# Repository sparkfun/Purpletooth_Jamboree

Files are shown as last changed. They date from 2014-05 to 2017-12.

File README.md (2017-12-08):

Purpletooth Jamboree Development Board
==================

Audio support board for the BC127 module from BlueCreation.

[Purpletooth Jamboree Development Board  
*Purpletooth Jamboree Development Board*](https://www.sparkfun.com/products/11924)

Design files and firmware files for the [Purpletooth Jamboree Development Board](https://www.sparkfun.com/products/11924).

Repository Contents
-------------------

* **/Fritzing** - Fritzing components for this board
* **/Hardware** - Eagle PCB layout files
* **/Libraries** - Library files for various platforms
* **/Production** - Files to support SparkFun production

License Information
-------------------

All contents of this repository are released under [Creative Commons Share-alike 4.0](http://creativecommons.org/licenses/by-sa/4.0/).

Authors: Mike Hord @ SparkFun Electonics

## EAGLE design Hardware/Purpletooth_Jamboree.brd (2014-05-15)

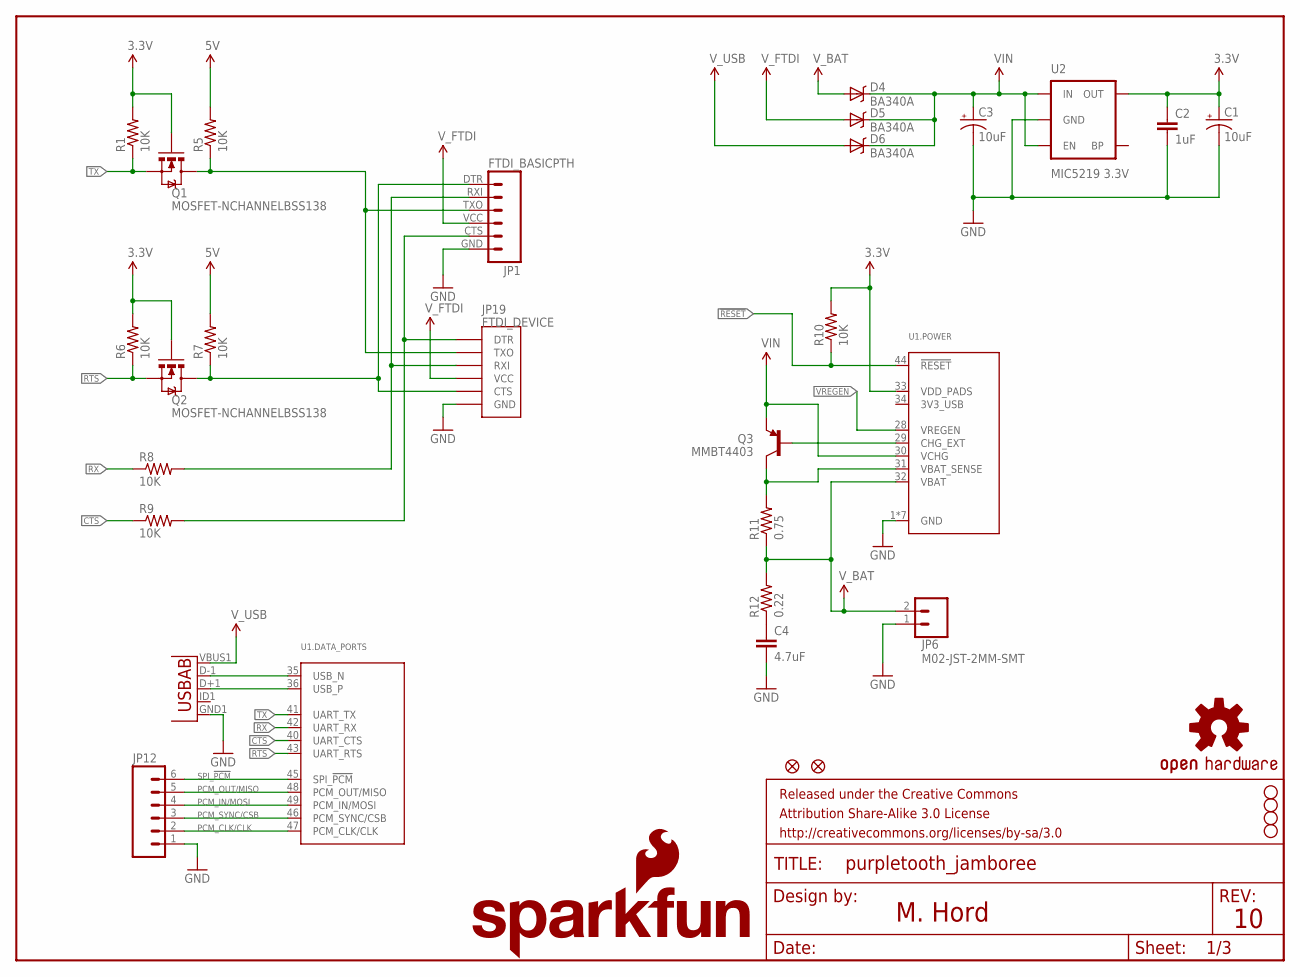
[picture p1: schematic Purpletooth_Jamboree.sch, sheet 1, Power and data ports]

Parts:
C1, C3: 10uF; EIA3216
C2: 1uF; 0805
C4: 4.7uF; 0603-CAP
D4, D5, D6: BA340A; SMA-DIODE
FID1, FID2: FIDUCIALUFIDUCIAL; MICRO-FIDUCIAL
FRAME1: FRAME-LETTER; CREATIVE_COMMONS
JP1: FTDI_BASICPTH; FTDI_BASIC
JP2: USB-ABCONN-11794; USB-AB-MICRO-SMD_V03
JP6: M02-JST-2MM-SMT; JST-2-SMD
JP12: M06SIP; 1X06
JP19: FTDI_DEVICE; FTDI_DEVICE_SIDE
LOGO1: OSHW-LOGOM; OSHW-LOGO-M
LOGO2: SFE_LOGO_NAME_FLAME.2_INCH; SFE_LOGO_NAME_FLAME_.2
Q1, Q2: MOSFET-NCHANNELBSS138; SOT23
Q3: MMBT4403; SOT23
R1, R5, R6, R7, R8, R9, R10: 10K; 0603-RES
R11: 0.75; 0805
R12: 0.22; 0805
STANDOFF1, STANDOFF2, STANDOFF3, STANDOFF4: STAND-OFF
U1: BC127EXTRA_PASTE; BC127_XTRA_PASTE
U2: MIC5219 3.3V; SOT23-5

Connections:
3.3V: C1.A (+), C2.1, Q1.1 (G), Q2.1 (G), R1.2, R6.2, R10.2, U1.33 (VDD_PADS), U2.5 (OUT); also elsewhere on the board
5V_CTS: JP1.CTS (5), JP19.P$1 (DTR), R9.2
5V_RTS: JP1.DTR (1), JP19.P$5 (CTS), Q2.3 (D), R7.1
5V_RX: JP1.RXI (2), JP19.P$3 (RXI), R8.2
5V_TX: JP1.TXO (3), JP19.P$2 (TXO), Q1.3 (D), R5.1
!RESET: R10.1, U1.44 (!RESET); also elsewhere on the board
CHG_EXT: Q3.1 (B), U1.29 (CHG_EXT)
CTS: R9.1, U1.40 (UART_CTS)
GND: C1.C (-), C2.2, C3.C (-), C4.2, JP1.GND (6), JP2.GND1 (GND), JP6.1 (2), JP12.1, JP19.P$6 (GND), U1.1 (GND), U1.2 (GND), U1.3 (GND), U1.4 (GND), U1.11 (GND), U1.22 (GND), U1.27 (GND), U2.2 (GND); also elsewhere on the board
unnamed: C4.1, R12.1
PCM_CLK/CLK: JP12.2, U1.47 (PCM_CLK/CLK)
PCM_IN/MOSI: JP12.4, U1.49 (PCM_IN/MOSI)
PCM_OUT/MISO: JP12.5, U1.48 (PCM_OUT/MISO)
PCM_SYNC/CSB: JP12.3, U1.46 (PCM_SYNC/CSB)
RTS: Q2.2 (S), R6.1, U1.43 (UART_RTS)
RX: R8.1, U1.42 (UART_RX)
SPI_!PCM: JP12.6, U1.45 (SPI_!PCM)
TX: Q1.2 (S), R1.1, U1.41 (UART_TX)
USB_N: JP2.D-1 (D-), U1.35 (USB_N)
USB_P: JP2.D+1 (D+), U1.36 (USB_P)
VBAT_SENSE: Q3.3 (C), R11.2, U1.31 (VBAT_SENSE)
VIN: C3.A (+), D4.C, D5.C, D6.C, Q3.2 (E), R5.2, R7.2, U1.30 (VCHG), U2.1 (IN), U2.3 (EN); also elsewhere on the board
VREGEN: U1.28 (VREGEN); also elsewhere on the board
V_BAT: D4.A, JP6.2 (1), R11.1, R12.2, U1.32 (VBAT)
V_FTDI: D5.A, JP1.VCC (4), JP19.P$4 (VCC)
V_USB: D6.A, JP2.VBUS1 (VBUS)

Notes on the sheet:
M. Hord

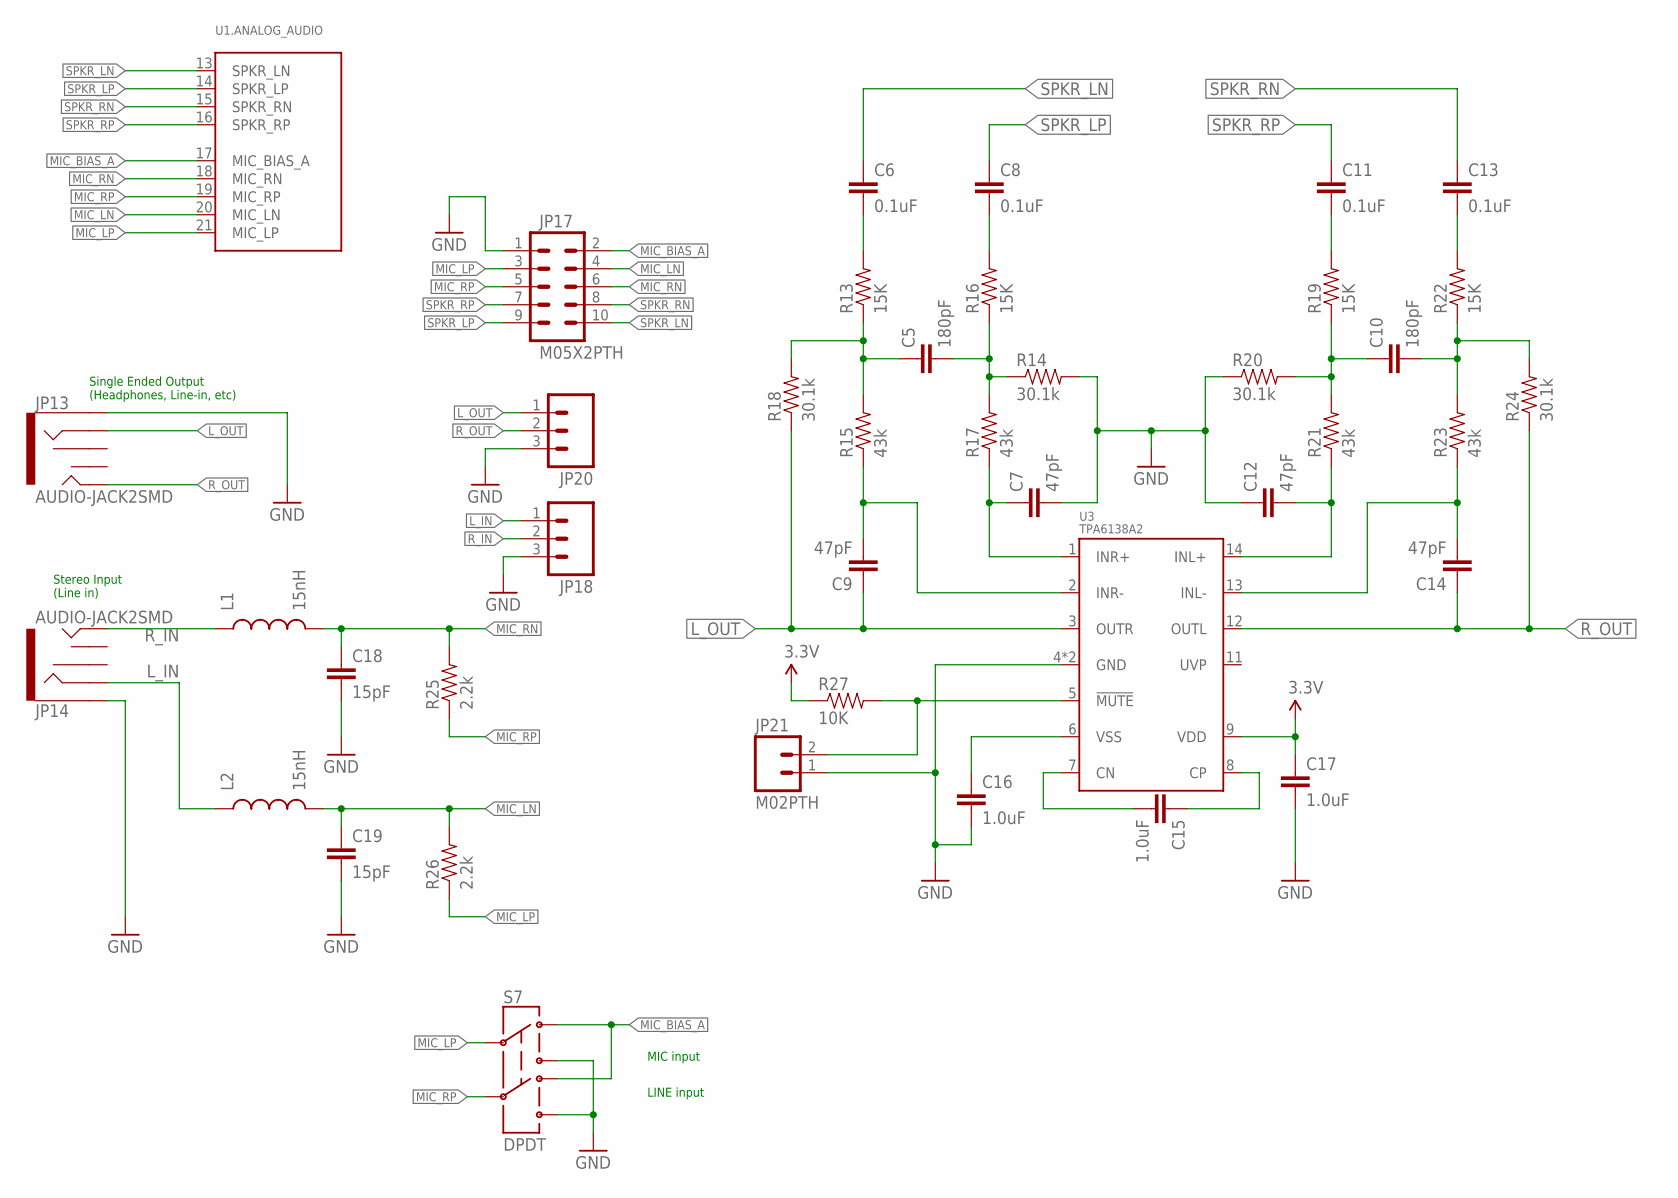
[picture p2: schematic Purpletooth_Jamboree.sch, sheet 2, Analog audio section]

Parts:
C5, C10: 180pF; 0603-CAP
C6, C8, C11, C13: 0.1uF; 0603-CAP
C7, C9, C12, C14: 47pF; 0603-CAP
C15, C16, C17: 1.0uF; 0603-CAP
C18, C19: 15pF; 0603-CAP
JP13, JP14: AUDIO-JACK2SMD; AUDIO-JACK-3.5MM-SMD
JP17: M05X2PTH; AVR_ICSP
JP18, JP20: M03PTH; 1X03
JP21: M02PTH; 1X02
L1, L2: 15nH; 0603
R13, R16, R19, R22: 15K; 0603-RES
R14, R18, R20, R24: 30.1k; 0603-RES
R15, R17, R21, R23: 43k; 0603-RES
R25, R26: 2.2k; 0603-RES
R27: 10K; 0603-RES
S7: DPDT; AYZ0202
U1: BC127EXTRA_PASTE; BC127_XTRA_PASTE
U3: TPA6138A2; TSSOP-14

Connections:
3.3V: C17.1, R27.1, U3.9 (VDD); also elsewhere on the board
GND: C7.2, C12.1, C16.2, C17.2, C18.2, C19.2, JP13.SLEEVE, JP14.SLEEVE, JP17.1, JP18.3, JP20.3, JP21.1, R14.2, R20.1, S7.3, S7.6, U3.4 (GND), U3.10 (GND); also elsewhere on the board
L_IN: JP14.RING, JP18.1, L2.1
L_OUT: C9.1, JP13.RING, JP20.1, R18.1, U3.3 (OUTR)
MIC_BIAS_A: JP17.2, S7.1, S7.4, U1.17 (MIC_BIAS_A)
MIC_LN: C19.1, JP17.4, L2.2, R26.2, U1.20 (MIC_LN)
MIC_LP: JP17.3, R26.1, S7.2, U1.21 (MIC_LP)
MIC_RN: C18.1, JP17.6, L1.2, R25.2, U1.18 (MIC_RN)
MIC_RP: JP17.5, R25.1, S7.5, U1.19 (MIC_RP)
unnamed: JP21.2, R27.2, U3.5 (!MUTE)
unnamed: C8.2, R16.2
unnamed: C6.2, R13.2
unnamed: C5.1, R13.1, R15.2, R18.2
unnamed: C9.2, R15.1, U3.2 (INR-)
unnamed: C7.1, R17.1, U3.1 (INR+)
unnamed: C5.2, R14.1, R16.1, R17.2
unnamed: C10.1, R19.1, R20.2, R21.2
unnamed: C12.2, R21.1, U3.14 (INL+)
unnamed: C11.2, R19.2
unnamed: C10.2, R22.1, R23.2, R24.2
unnamed: C13.2, R22.2
unnamed: C14.2, R23.1, U3.13 (INL-)
unnamed: C16.1, U3.6 (VSS)
unnamed: C15.2, U3.7 (CN)
unnamed: C15.1, U3.8 (CP)
R_IN: JP14.TIP, JP18.2, L1.1
R_OUT: C14.1, JP13.TIP, JP20.2, R24.1, U3.12 (OUTL)
SPKR_LN: C6.1, JP17.10, U1.13 (SPKR_LN)
SPKR_LP: C8.1, JP17.9, U1.14 (SPKR_LP)
SPKR_RN: C13.1, JP17.8, U1.15 (SPKR_RN)
SPKR_RP: C11.1, JP17.7, U1.16 (SPKR_RP)

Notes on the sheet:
Single Ended Output (Headphones, Line-in, etc)
Stereo Input (Line in)
MIC input
LINE input

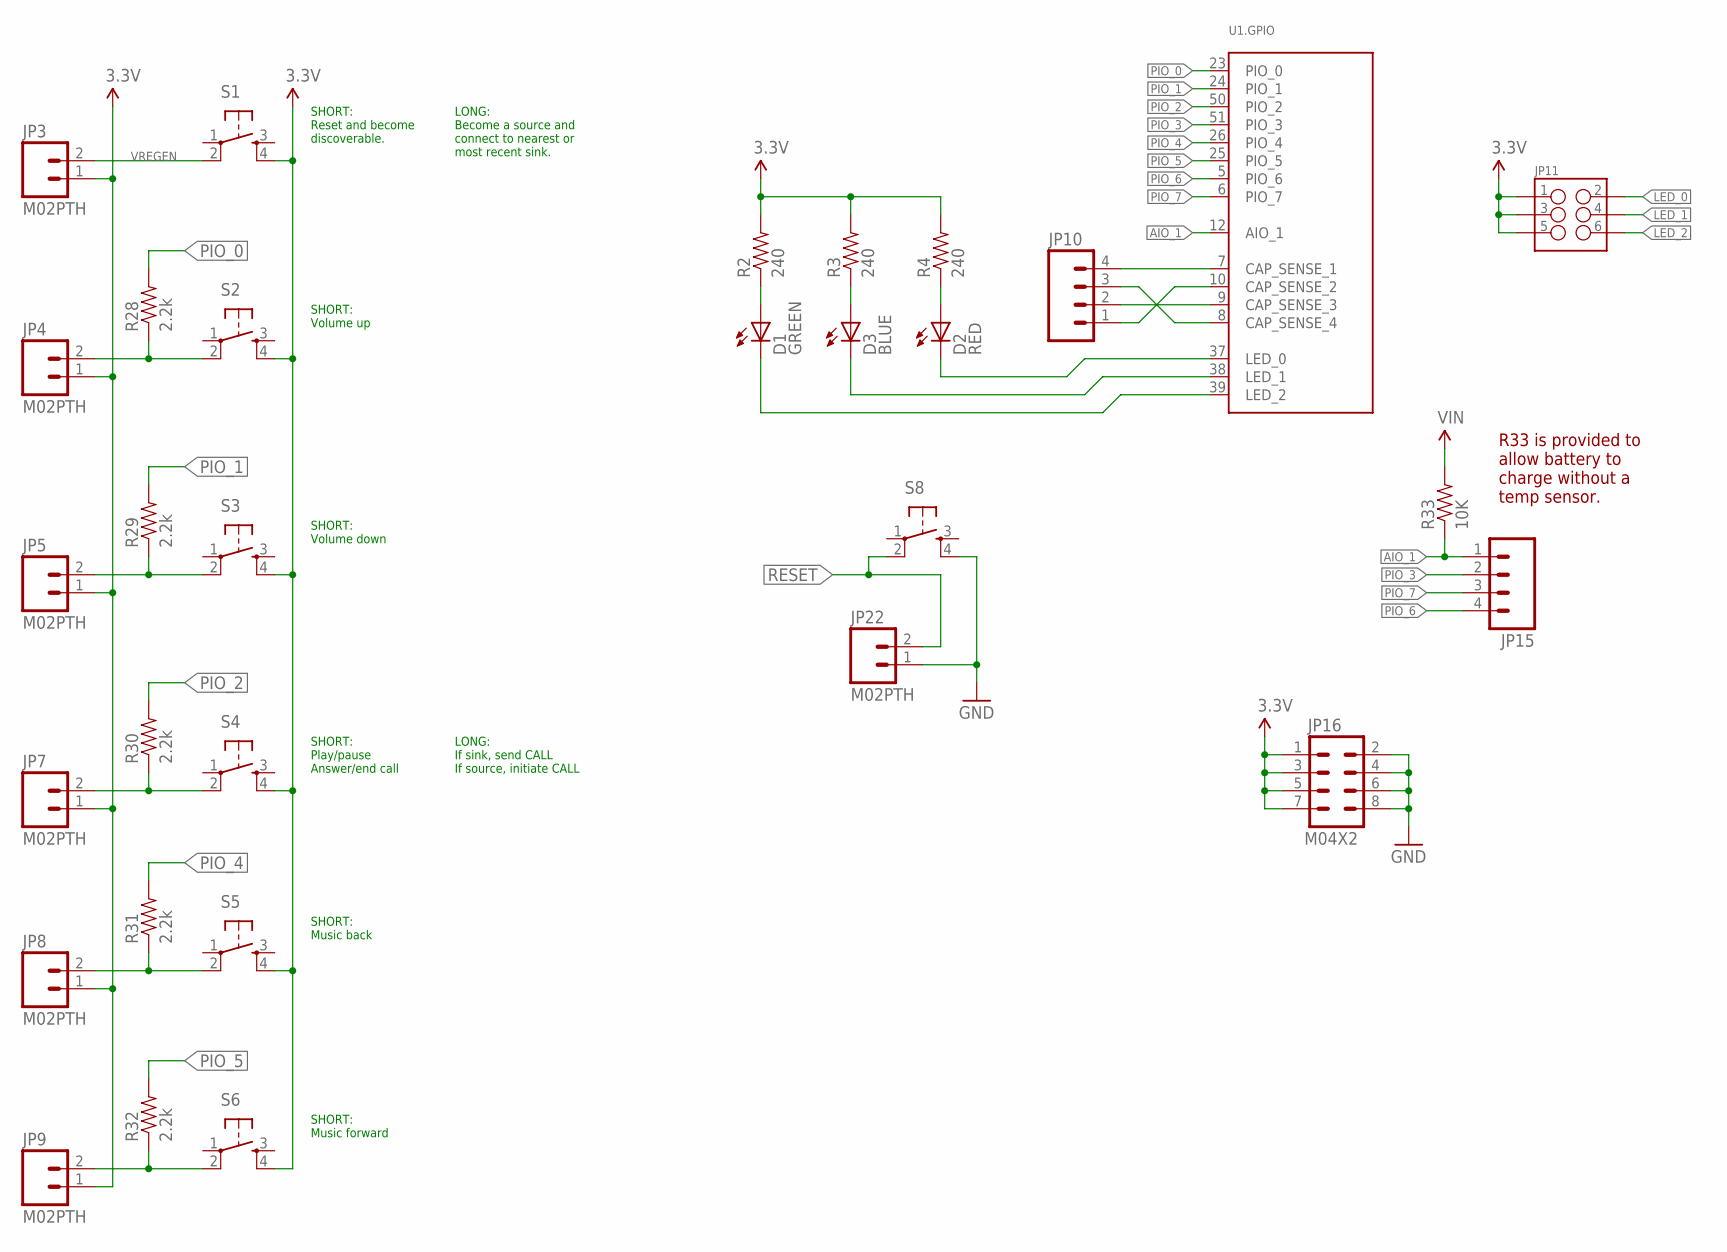
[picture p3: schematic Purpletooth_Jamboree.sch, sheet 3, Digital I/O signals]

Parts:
D1: GREEN; LED-0603
D2: RED; LED-0603
D3: BLUE; LED-0603
JP3, JP4, JP5, JP7, JP8, JP9, JP22: M02PTH; 1X02
JP10, JP15: M04PTH; 1X04
JP11: M03X22X3_SILK_SM; 2X3
JP16: M04X2; 2X4
R2, R3, R4: 240; 0603-RES
R28, R29, R30, R31, R32: 2.2k; 0603-RES
R33: 10K; 0603-RES
S1, S2, S3, S4, S5, S6, S8: TAC_SWITCHSMD; TACTILE_SWITCH_SMD
U1: BC127EXTRA_PASTE; BC127_XTRA_PASTE

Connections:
3.3V: JP3.1, JP4.1, JP5.1, JP7.1, JP8.1, JP9.1, JP11.1, JP11.3, JP11.5, JP16.1, JP16.3, JP16.5, JP16.7, R2.2, R3.2, R4.2, S1.4, S2.4, S3.4, S4.4, S5.4, S6.4; also elsewhere on the board
!RESET: JP22.2, S8.2; also elsewhere on the board
AIO_1: JP15.1, R33.1, U1.12 (AIO_1)
CAP_SENSE-4: JP10.3, U1.8 (CAP_SENSE_4)
CAP_SENSE_1: JP10.4, U1.7 (CAP_SENSE_1)
CAP_SENSE_2: JP10.1, U1.10 (CAP_SENSE_2)
CAP_SENSE_3: JP10.2, U1.9 (CAP_SENSE_3)
GND: JP16.2, JP16.4, JP16.6, JP16.8, JP22.1, S8.4; also elsewhere on the board
LED_0: D2.C, JP11.2, U1.37 (LED_0)
LED_1: D3.C, JP11.4, U1.38 (LED_1)
LED_2: D1.C, JP11.6, U1.39 (LED_2)
unnamed: D3.A, R3.1
unnamed: D2.A, R4.1
unnamed: D1.A, R2.1
unnamed: JP4.2, R28.1, S2.2
unnamed: JP5.2, R29.1, S3.2
unnamed: JP7.2, R30.1, S4.2
unnamed: JP8.2, R31.1, S5.2
unnamed: JP9.2, R32.1, S6.2
PIO_0: R28.2, U1.23 (PIO_0)
PIO_1: R29.2, U1.24 (PIO_1)
PIO_2: R30.2, U1.50 (PIO_2)
PIO_3: JP15.2, U1.51 (PIO_3)
PIO_4: R31.2, U1.26 (PIO_4)
PIO_5: R32.2, U1.25 (PIO_5)
PIO_6: JP15.4, U1.5 (PIO_6)
PIO_7: JP15.3, U1.6 (PIO_7)
VIN: R33.2; also elsewhere on the board
VREGEN: JP3.2, S1.2; also elsewhere on the board

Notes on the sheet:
SHORT: Reset and become discoverable.
LONG: Become a source and connect to nearest or most recent sink.
SHORT: Volume up
SHORT: Volume down
SHORT: Play/pause Answer/end call
LONG: If sink, send CALL If source, initiate CALL
SHORT: Music back
SHORT: Music forward
R33 is provided to allow battery to charge without a temp sensor.

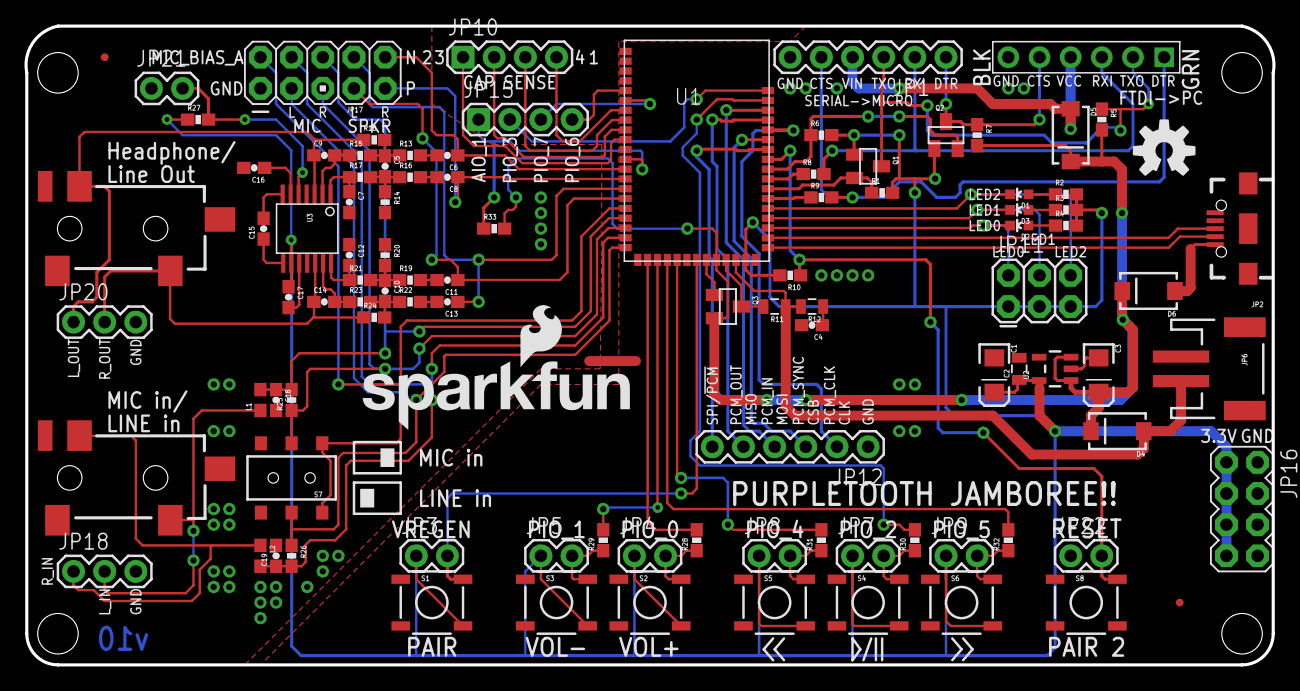
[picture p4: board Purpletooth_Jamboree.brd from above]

Board: 2 copper layers, 101.7 x 52.1 mm, 105 parts (0 on the bottom side), 79 nets.

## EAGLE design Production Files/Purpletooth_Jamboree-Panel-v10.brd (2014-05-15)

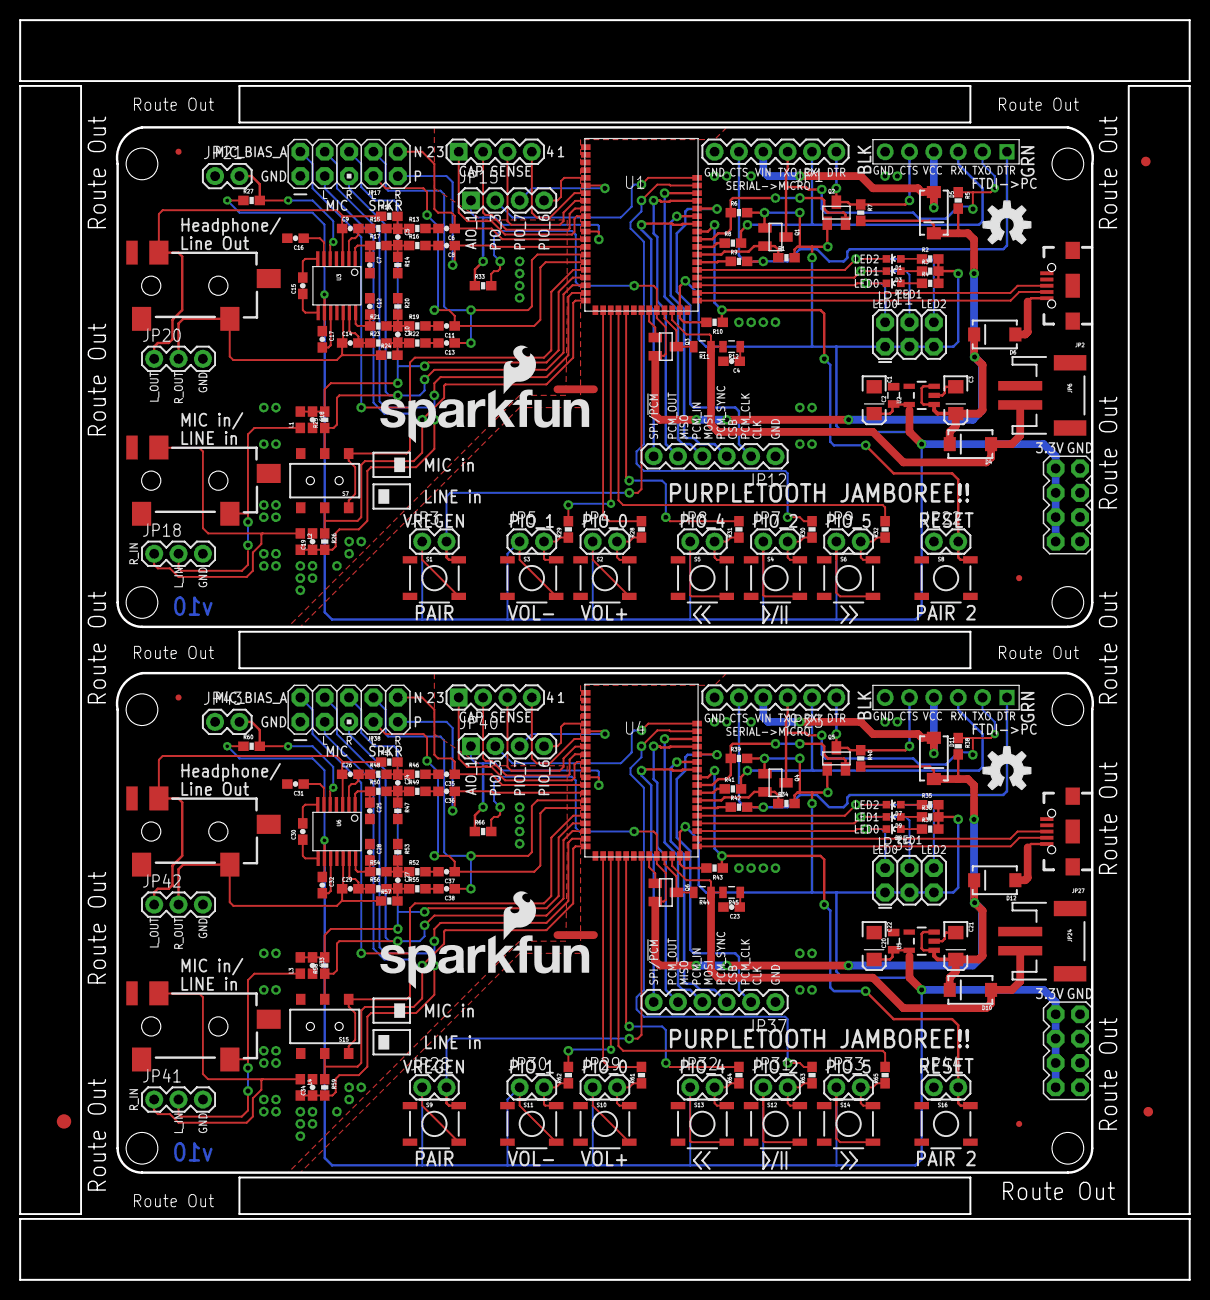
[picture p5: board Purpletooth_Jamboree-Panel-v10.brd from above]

Board: 2 copper layers, 121.9 x 131.3 mm, 211 parts (0 on the bottom side), 158 nets.

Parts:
C1, C3, C21, C22: 10uF; EIA3216
C2, C20: 1uF; 0805
C4, C23: 4.7uF; 0603-CAP
C5, C10, C24, C27: 180pF; 0603-CAP
C6, C8, C11, C13, C35, C36, C37, C38: 0.1uF; 0603-CAP
C7, C9, C12, C14, C25, C26, C28, C29: 47pF; 0603-CAP
C15, C16, C17, C30, C31, C32: 1.0uF; 0603-CAP
C18, C19, C33, C34: 15pF; 0603-CAP
D1, D7: GREEN; LED-0603
D2, D8: RED; LED-0603
D3, D9: BLUE; LED-0603
D4, D5, D6, D10, D11, D12: BA340A; SMA-DIODE
E$1: FIDUCIAL-1.5X3
E$13, E$14: FIDUCIAL-1X2
FID1, FID2, FID3, FID4: FIDUCIALUFIDUCIAL; MICRO-FIDUCIAL
JP1, JP23: FTDI_BASICPTH; FTDI_BASIC
JP2, JP27: USB-AB-MICRO-SMD_V03
JP3, JP4, JP5, JP7, JP8, JP9, JP21, JP22, JP28, JP29, JP30, JP31, JP32, JP33, JP43, JP44: M02PTH; 1X02
JP6, JP24: M02-JST-2MM-SMT; JST-2-SMD
JP10, JP15, JP34, JP40: 1X04
JP11, JP35: 2X3
JP12, JP37: 1X06
JP13, JP14, JP25, JP26: AUDIO-JACK2SMD; AUDIO-JACK-3.5MM-SMD
JP16, JP36: M04X2; 2X4
JP17, JP38: M05X2PTH; AVR_ICSP
JP18, JP20, JP41, JP42: 1X03
JP19, JP39: FTDI_DEVICE; FTDI_DEVICE_SIDE
L1, L2, L3, L4: 15nH; 0603
LOGO1, LOGO3: OSHW-LOGOM; OSHW-LOGO-M
LOGO2, LOGO4: SFE_LOGO_NAME_FLAME.2_INCH; SFE_LOGO_NAME_FLAME_.2
Q1, Q2, Q4, Q5: MOSFET-NCHANNELBSS138; SOT23
Q3, Q6: MMBT4403; SOT23
R1, R5, R6, R7, R8, R9, R10, R27, R33, R34, R38, R39, R40, R41, R42, R43, R60, R66: 10K; 0603-RES
R2, R3, R4, R35, R36, R37: 240; 0603-RES
R11, R44: 0.75; 0805
R12, R45: 0.22; 0805
R13, R16, R19, R22, R46, R49, R52, R55: 15K; 0603-RES
R14, R18, R20, R24, R47, R51, R53, R57: 30.1k; 0603-RES
R15, R17, R21, R23, R48, R50, R54, R56: 43k; 0603-RES
R25, R26, R28, R29, R30, R31, R32, R58, R59, R61, R62, R63, R64, R65: 2.2k; 0603-RES
S1, S2, S3, S4, S5, S6, S8, S9, S10, S11, S12, S13, S14, S16: TACTILE_SWITCH_SMD
S7, S15: DPDT; AYZ0202
STANDOFF1, STANDOFF2, STANDOFF3, STANDOFF4, STANDOFF5, STANDOFF6, STANDOFF7, STANDOFF8: STAND-OFF
U1, U4: BC127_XTRA_PASTE
U2, U5: MIC5219 3.3V; SOT23-5
U3, U6: TPA6138A2; TSSOP-14

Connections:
3.3V: C1.A, C2.1, C17.1, JP3.1, JP4.1, JP5.1, JP7.1, JP8.1, JP9.1, JP11.1, JP11.3, JP11.5, JP16.1, JP16.3, JP16.5, JP16.7, Q1.1, Q2.1, R1.2, R2.2, R3.2, R4.2, R6.2, R10.2, R27.1, S1.4, S2.4, S3.4, S4.4, S5.4, S6.4, U1.33, U2.5, U3.9
3.3V1: C20.1, C22.A, C32.1, JP28.1, JP29.1, JP30.1, JP31.1, JP32.1, JP33.1, JP35.1, JP35.3, JP35.5, JP36.1, JP36.3, JP36.5, JP36.7, Q4.1, Q5.1, R34.2, R35.2, R36.2, R37.2, R39.2, R43.2, R60.1, S9.4, S10.4, S11.4, S12.4, S13.4, S14.4, U4.33, U5.5, U6.9
5V_CTS: JP1.CTS, JP19.P$1, R9.2
5V_CTS1: JP23.CTS, JP39.P$1, R42.2
5V_RTS: JP1.DTR, JP19.P$5, Q2.3, R7.1
5V_RTS1: JP23.DTR, JP39.P$5, Q5.3, R40.1
5V_RX: JP1.RXI, JP19.P$3, R8.2
5V_RX1: JP23.RXI, JP39.P$3, R41.2
5V_TX: JP1.TXO, JP19.P$2, Q1.3, R5.1
5V_TX1: JP23.TXO, JP39.P$2, Q4.3, R38.1
!RESET: JP22.2, R10.1, S8.2, U1.44
!RESET1: JP44.2, R43.1, S16.2, U4.44
AIO_1: JP15.1, R33.1, U1.12
AIO_2: JP40.1, R66.1, U4.12
CAP_SENSE-1: JP34.3, U4.8
CAP_SENSE-4: JP10.3, U1.8
CAP_SENSE_1: JP10.4, U1.7
CAP_SENSE_2: JP10.1, U1.10
CAP_SENSE_3: JP10.2, U1.9
CAP_SENSE_4: JP34.2, U4.9
CAP_SENSE_5: JP34.4, U4.7
CAP_SENSE_6: JP34.1, U4.10
CHG_EXT: Q3.1, U1.29
CHG_EXT1: Q6.1, U4.29
CTS: R9.1, U1.40
CTS1: R42.1, U4.40
GND: C1.C, C2.2, C3.C, C4.2, C7.2, C12.1, C16.2, C17.2, C18.2, C19.2, JP1.GND, JP2.GND1, JP6.1, JP12.1, JP13.SLEEVE, JP14.SLEEVE, JP16.2, JP16.4, JP16.6, JP16.8, JP17.1, JP18.3, JP19.P$6, JP20.3, JP21.1, JP22.1, R14.2, R20.1, S7.3, S7.6, S8.4, U1.1, U1.2, U1.3, U1.4, U1.11, U1.22, U1.27, U2.2, U3.4, U3.10
GND1: C20.2, C21.C, C22.C, C23.2, C25.2, C28.1, C31.2, C32.2, C33.2, C34.2, JP23.GND, JP24.1, JP25.SLEEVE, JP26.SLEEVE, JP27.GND1, JP36.2, JP36.4, JP36.6, JP36.8, JP37.1, JP38.1, JP39.P$6, JP41.3, JP42.3, JP43.1, JP44.1, R47.2, R53.1, S15.3, S15.6, S16.4, U4.1, U4.2, U4.3, U4.4, U4.11, U4.22, U4.27, U5.2, U6.4, U6.10
LED_0: D2.C, JP11.2, U1.37
LED_1: D3.C, JP11.4, U1.38
LED_2: D1.C, JP11.6, U1.39
LED_3: D7.C, JP35.6, U4.39
LED_4: D9.C, JP35.4, U4.38
LED_5: D8.C, JP35.2, U4.37
L_IN: JP14.RING, JP18.1, L2.1
L_IN1: JP26.RING, JP41.1, L4.1
L_OUT: C9.1, JP13.RING, JP20.1, R18.1, U3.3
L_OUT1: C26.1, JP25.RING, JP42.1, R51.1, U6.3
MIC_BIAS_A: JP17.2, S7.1, S7.4, U1.17
MIC_BIAS_A1: JP38.2, S15.1, S15.4, U4.17
MIC_LN: C19.1, JP17.4, L2.2, R26.2, U1.20
MIC_LN1: C34.1, JP38.4, L4.2, R59.2, U4.20
MIC_LP: JP17.3, R26.1, S7.2, U1.21
MIC_LP1: JP38.3, R59.1, S15.2, U4.21
MIC_RN: C18.1, JP17.6, L1.2, R25.2, U1.18
MIC_RN1: C33.1, JP38.6, L3.2, R58.2, U4.18
MIC_RP: JP17.5, R25.1, S7.5, U1.19
MIC_RP1: JP38.5, R58.1, S15.5, U4.19
unnamed: JP21.2, R27.2, U3.5
unnamed: D3.A, R3.1
unnamed: D9.A, R36.1
unnamed: C8.2, R16.2
unnamed: C6.2, R13.2
unnamed: D2.A, R4.1
unnamed: D1.A, R2.1
unnamed: C5.1, R13.1, R15.2, R18.2
unnamed: C9.2, R15.1, U3.2
unnamed: JP4.2, R28.1, S2.2
unnamed: JP5.2, R29.1, S3.2
unnamed: C7.1, R17.1, U3.1
unnamed: C5.2, R14.1, R16.1, R17.2
unnamed: JP7.2, R30.1, S4.2
unnamed: JP8.2, R31.1, S5.2
unnamed: C10.1, R19.1, R20.2, R21.2
unnamed: C12.2, R21.1, U3.14
unnamed: C11.2, R19.2
unnamed: C10.2, R22.1, R23.2, R24.2
unnamed: C13.2, R22.2
unnamed: C14.2, R23.1, U3.13
unnamed: JP9.2, R32.1, S6.2
unnamed: D8.A, R37.1
unnamed: C16.1, U3.6
unnamed: C15.2, U3.7
unnamed: C15.1, U3.8
unnamed: D7.A, R35.1
unnamed: C4.1, R12.1
unnamed: C23.1, R45.1
unnamed: C36.2, R49.2
unnamed: C35.2, R46.2
unnamed: C24.1, R46.1, R48.2, R51.2
unnamed: C26.2, R48.1, U6.2
unnamed: C25.1, R50.1, U6.1
unnamed: C24.2, R47.1, R49.1, R50.2
unnamed: C27.1, R52.1, R53.2, R54.2
unnamed: C28.2, R54.1, U6.14
unnamed: C37.2, R52.2
unnamed: C27.2, R55.1, R56.2, R57.2
unnamed: C38.2, R55.2
unnamed: C29.2, R56.1, U6.13
unnamed: C31.1, U6.6
unnamed: C30.2, U6.7
unnamed: C30.1, U6.8
unnamed: JP43.2, R60.2, U6.5
unnamed: JP29.2, R61.1, S10.2
unnamed: JP30.2, R62.1, S11.2
unnamed: JP31.2, R63.1, S12.2
unnamed: JP32.2, R64.1, S13.2
unnamed: JP33.2, R65.1, S14.2
PCM_CLK/CLK: JP12.2, U1.47
PCM_CLK/CLK1: JP37.2, U4.47
PCM_IN/MOSI: JP12.4, U1.49
PCM_IN/MOSI1: JP37.4, U4.49
PCM_OUT/MISO: JP12.5, U1.48
PCM_OUT/MISO1: JP37.5, U4.48
PCM_SYNC/CSB: JP12.3, U1.46
PCM_SYNC/CSB1: JP37.3, U4.46
PIO_0: R28.2, U1.23
PIO_1: R29.2, U1.24
PIO_2: R30.2, U1.50
PIO_3: JP15.2, U1.51
PIO_4: R31.2, U1.26
PIO_5: R32.2, U1.25
PIO_6: JP15.4, U1.5
PIO_7: JP15.3, U1.6
PIO_8: R61.2, U4.23
PIO_9: R65.2, U4.25
PIO_10: JP40.4, U4.5
PIO_11: JP40.3, U4.6
PIO_12: R64.2, U4.26
PIO_13: JP40.2, U4.51
PIO_14: R63.2, U4.50
PIO_15: R62.2, U4.24
RTS: Q2.2, R6.1, U1.43
RTS1: Q5.2, R39.1, U4.43
RX: R8.1, U1.42
RX1: R41.1, U4.42
R_IN: JP14.TIP, JP18.2, L1.1
R_IN1: JP26.TIP, JP41.2, L3.1
R_OUT: C14.1, JP13.TIP, JP20.2, R24.1, U3.12
R_OUT1: C29.1, JP25.TIP, JP42.2, R57.1, U6.12
SPI_!PCM: JP12.6, U1.45
SPI_!PCM1: JP37.6, U4.45
SPKR_LN: C6.1, JP17.10, U1.13
SPKR_LN1: C35.1, JP38.10, U4.13
SPKR_LP: C8.1, JP17.9, U1.14
SPKR_LP1: C36.1, JP38.9, U4.14
SPKR_RN: C13.1, JP17.8, U1.15
SPKR_RN1: C38.1, JP38.8, U4.15
SPKR_RP: C11.1, JP17.7, U1.16
SPKR_RP1: C37.1, JP38.7, U4.16
TX: Q1.2, R1.1, U1.41
TX1: Q4.2, R34.1, U4.41
USB_N: JP2.D-1, U1.35
USB_N1: JP27.D-1, U4.35
USB_P: JP2.D+1, U1.36
USB_P1: JP27.D+1, U4.36
VBAT_SENSE: Q3.3, R11.2, U1.31
VBAT_SENSE1: Q6.3, R44.2, U4.31
VIN: C3.A, D4.C, D5.C, D6.C, Q3.2, R5.2, R7.2, R33.2, U1.30, U2.1, U2.3
VIN1: C21.A, D10.C, D11.C, D12.C, Q6.2, R38.2, R40.2, R66.2, U4.30, U5.1, U5.3
VREGEN: JP3.2, S1.2, U1.28
VREGEN1: JP28.2, S9.2, U4.28
V_BAT: D4.A, JP6.2, R11.1, R12.2, U1.32
V_BAT1: D10.A, JP24.2, R44.1, R45.2, U4.32
V_FTDI: D5.A, JP1.VCC, JP19.P$4
V_FTDI1: D11.A, JP23.VCC, JP39.P$4
V_USB: D6.A, JP2.VBUS1
V_USB1: D12.A, JP27.VBUS1

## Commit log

2013-06-13 Initial commit, pre-review
    [Purpletooth_Jambot.brd, Purpletooth_Jambot.sch]
2013-06-18 Roll changes from design review in.
    [Purpletooth_Jambot.brd, Purpletooth_Jambot.sch]
2013-06-18 Files ready for protos
    [Purpletooth_Jamboree.brd, Purpletooth_Jamboree.sch]
2013-10-07 Roll to next round of protos. - fix FTDI header pinouts - new USB footprint - add resistor to defeat charger temp sense - remove inductor to ground on audio input - fix buttons (add inline resistor, 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
    [Purpletooth_Jamboree.brd, Purpletooth_Jamboree.sch]
2013-10-07 Library update for connectors lib
    [Purpletooth_Jamboree.brd, Purpletooth_Jamboree.sch]
2013-10-28 Transition to v10 for production - change labels on board and schematic - move top edge of board .05" up, to prevent module overhang from interfering with panelization
    [Purpletooth_Jamboree.brd, Purpletooth_Jamboree.sch]
2013-10-28 Added micro fiducial to board
    [Purpletooth_Jamboree-Panel-v10.brd, Purpletooth_Jamboree.brd, Purpletooth_Jamboree.sch]
2013-10-28 Created Panel
    normal sized panel
    [Purpletooth_Jamboree-Panel-v10.brd]
2014-01-09 Replaced BC127 PKG w/ BC127_EXTRA_PASTE PKG
    -Replaced the existing BC127 PKG with the BC127_EXTRA_PASTE PKG that
    solved the cold-joint issues on the BC127 Module for the BC127 BOB (adds
    extra paste to module pads).
    -No hardware changes, just a stencil change.
    [Purpletooth_Jamboree.brd, Purpletooth_Jamboree.sch]
2014-01-09 added over paste for the module to panel
    [Purpletooth_Jamboree-Panel-v10.brd]
2015-04-27 Squashed 'Libraries/Arduino/' content from commit 6404651
    git-subtree-dir: Libraries/Arduino
    git-subtree-split: 6404651582bfe3aa4f8bdf3988896212e57d584d

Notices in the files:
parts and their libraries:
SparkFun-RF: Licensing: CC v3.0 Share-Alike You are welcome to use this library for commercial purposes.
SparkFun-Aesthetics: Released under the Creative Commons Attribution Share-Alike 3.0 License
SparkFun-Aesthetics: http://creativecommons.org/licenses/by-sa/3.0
